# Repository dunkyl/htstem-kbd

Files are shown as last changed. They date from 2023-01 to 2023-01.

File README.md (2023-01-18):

# HTSTEM Keyboard

CAD files for the HTSTEM keyboard.

## Macro12

Test board for the project. 12 keys, 12 addressible LEDs, and rotary encoder. First time I've actually gone through with ordering a PCB to be made.

Source code for firmware is at [another repo](https://github.com/dunkyl/dunkylmacro12).

BOM for macro12:

| Quantity | Description | Link | Note |
| --- | --- | --- | --- |
| 1 | Teensy 2.0 | https://www.pjrc.com/store/teensy.html | Or any compatible microcontroller. I used an [Elite-C from Keebio](https://keeb.io/collections/diy-parts/products/elite-c-low-profile-version-usb-c-pro-micro-replacement-atmega32u4) |
| 1 | PEC11 12mm Rotary Encoder | https://www.digikey.com/en/products/detail/bourns-inc/PEC11L-4220F-S0015/2440942 | |
| 1 | Knob | https://www.digikey.com/en/products/detail/sparkfun-electronics/COM-10001/7229870 | Any knob really |
| 12 | Addressible LED SK6812MINI-E Reverse Mount | https://www.adafruit.com/product/4960 | 10 pack so buy qty 2 |
| 12 | Diode 1N4148FS-ND | https://www.digikey.com/en/products/detail/onsemi/1N4148/458603?s=N4IgTCBcDaIIwDkAsckA4BiBlAtAgIiALoC%2BQA | Or similiar |
| 12 | Key Switch | - | Your choice |
| 12 | Key Cap | - | Your choice |
| 1 | 3D Printed Case | - | Source files here |
| 1 | PCB | - | Source files here |
| 4 | Rubber Feet | https://www.adafruit.com/product/550 | Optional |
| - | Some tape | - | To hold the case halves together. |

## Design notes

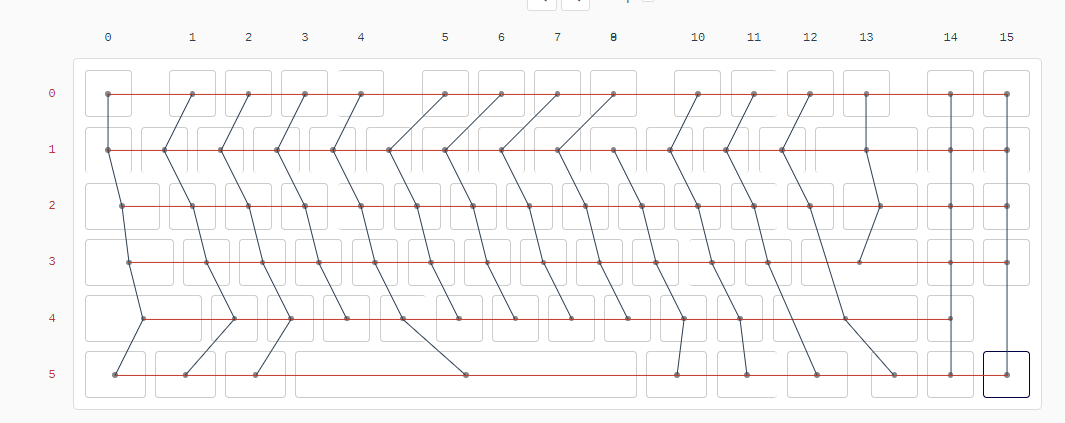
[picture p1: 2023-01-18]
keyboard/Screenshot 2022-04-16 083857.png

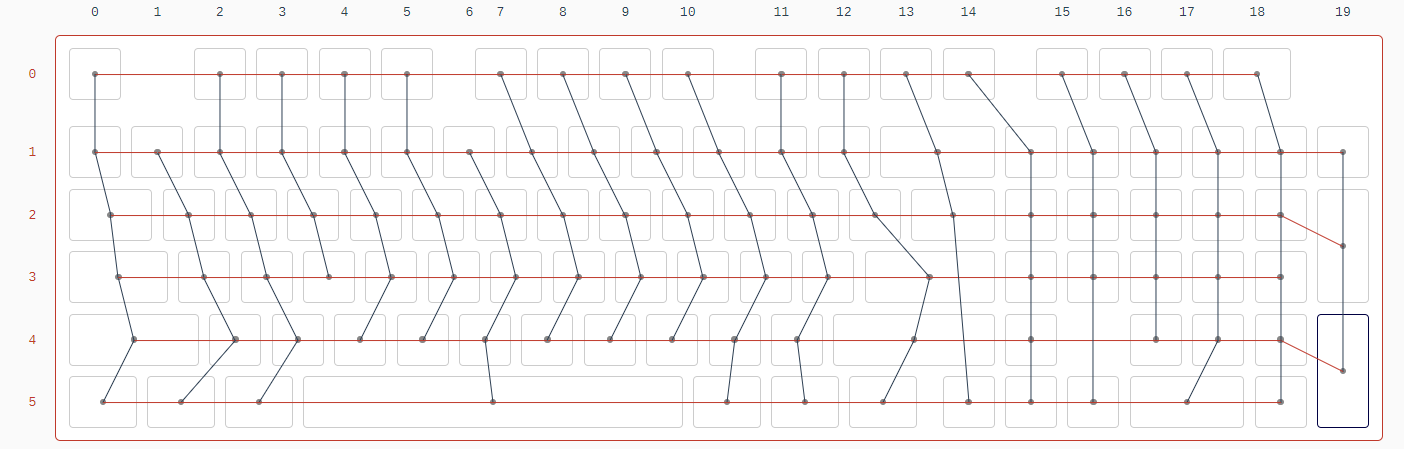
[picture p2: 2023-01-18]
keyboard/Screenshot 2021-11-04 011222.png

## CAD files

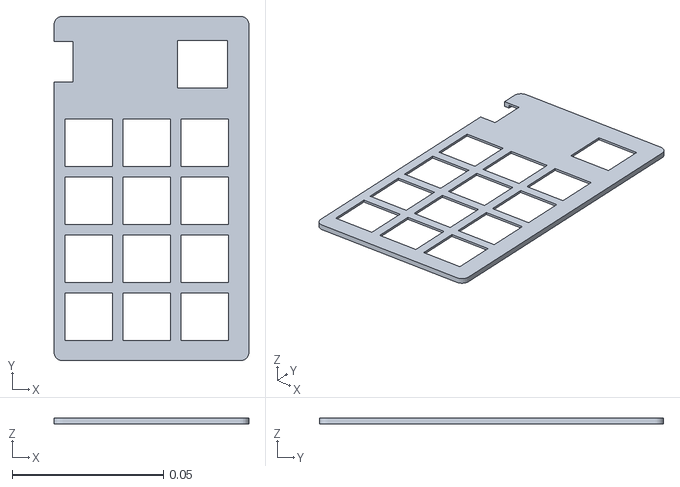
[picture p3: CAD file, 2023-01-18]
macro12/3D Print/lid.stl
0.0645 x 0.114 x 0.00185

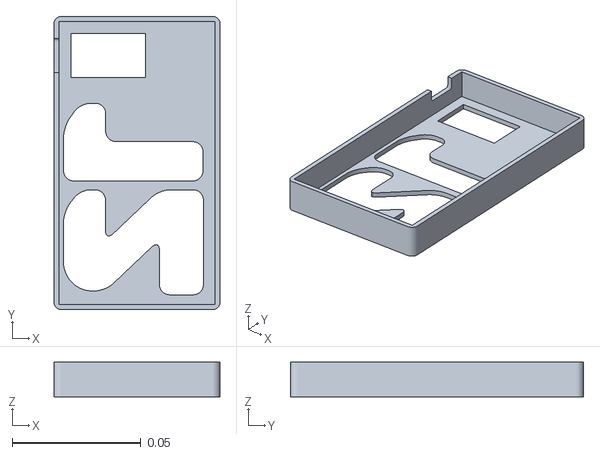
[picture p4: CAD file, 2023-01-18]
macro12/3D Print/casebottom.stl
0.0645 x 0.114 x 0.0135

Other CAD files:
htstem keyboard.blend

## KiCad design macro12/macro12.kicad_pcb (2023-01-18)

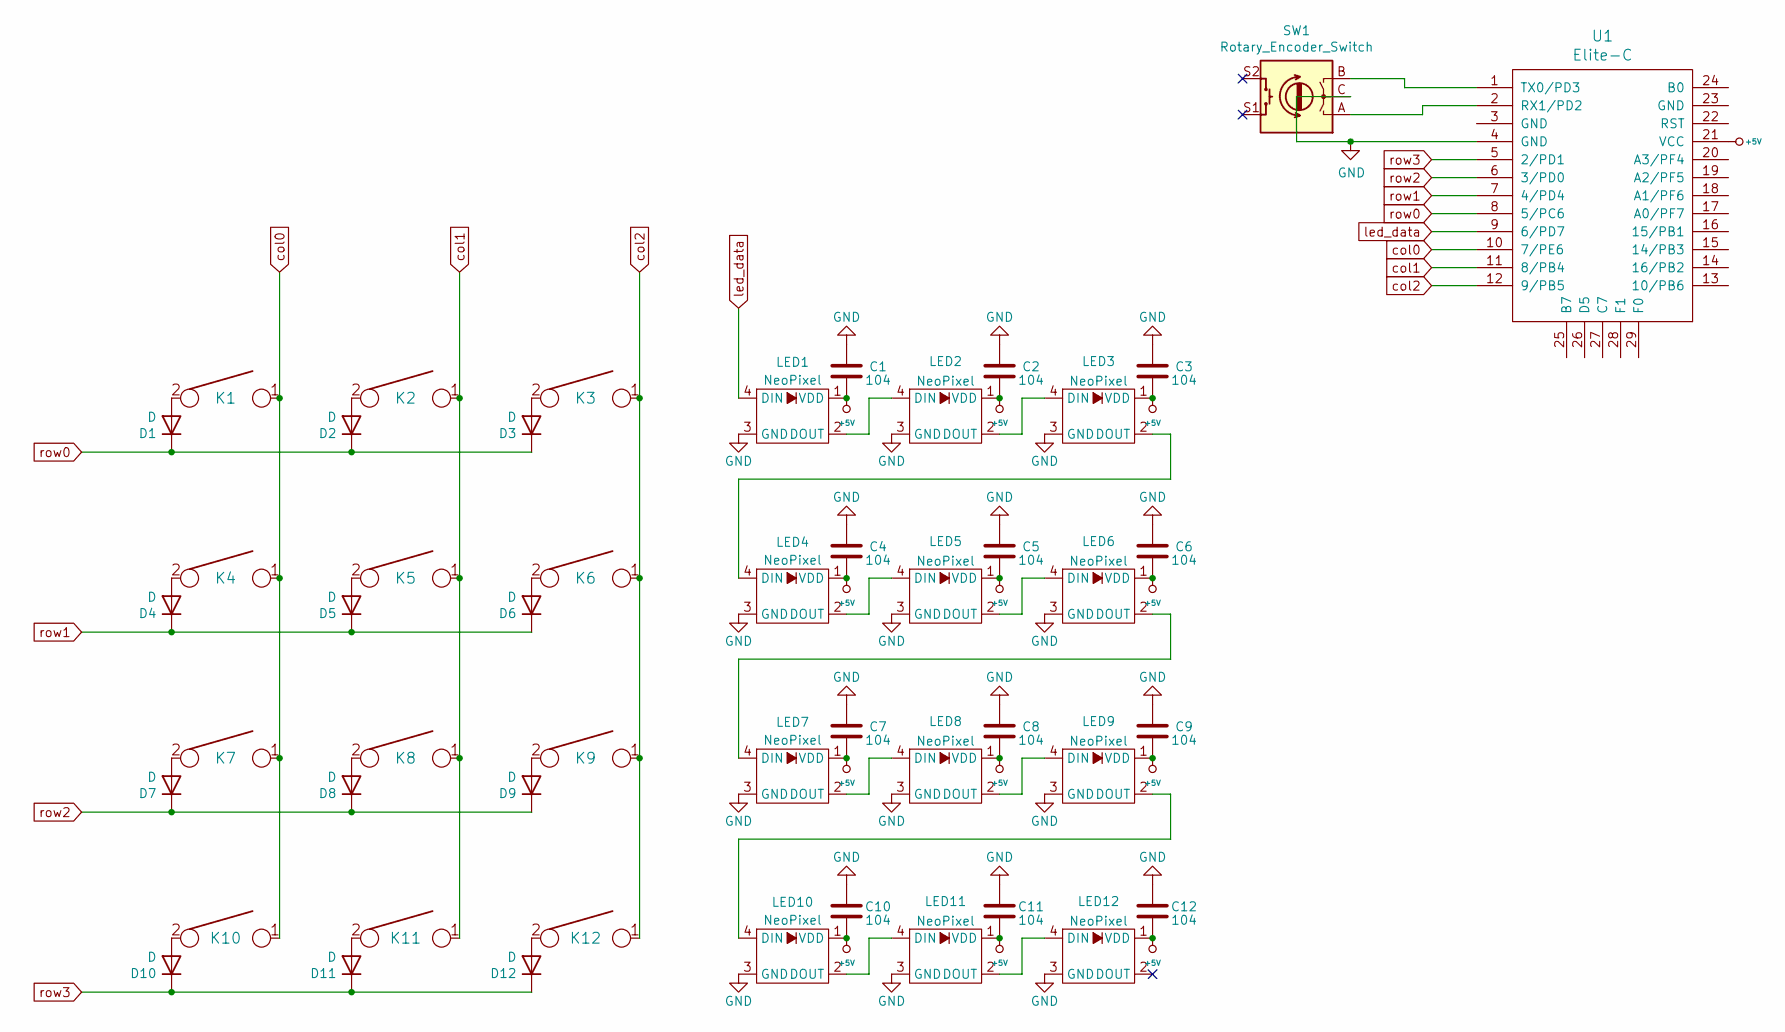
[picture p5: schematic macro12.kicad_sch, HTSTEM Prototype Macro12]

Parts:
C1, C2, C3, C4, C5, C6, C7, C8, C9, C10, C11, C12: 104; C_0805_2012Metric_Pad1.18x1.45mm_HandSolder
D1, D2, D3, D4, D5, D6, D7, D8, D9, D10, D11, D12: D; D_SOD123_axial
K1, K2, K3, K4, K5, K6, K7, K8, K9, K10, K11, K12: KEYSW; Mx_Alps_100
LED1, LED2, LED3, LED4, LED5, LED6, LED7, LED8, LED9, LED10, LED11, LED12: NeoPixel; Adafruit NeoPixel SK6812_E
SW1: Rotary_Encoder_Switch; RotaryEncoder_Alps_EC11E-Switch_Vertical_H20mm
U1: Elite-C; Elite-C-castellated-29pin-holes

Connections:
+5V: C1.1, C2.1, C3.1, C4.1, C5.1, C6.1, C7.1, C8.1, C9.1, C10.1, C11.1, C12.1, LED1.1 (VDD), LED2.1 (VDD), LED3.1 (VDD), LED4.1 (VDD), LED5.1 (VDD), LED6.1 (VDD), LED7.1 (VDD), LED8.1 (VDD), LED9.1 (VDD), LED10.1 (VDD), LED11.1 (VDD), LED12.1 (VDD), U1.21 (VCC)
GND: C1.2, C2.2, C3.2, C4.2, C5.2, C6.2, C7.2, C8.2, C9.2, C10.2, C11.2, C12.2, LED1.3 (GND), LED2.3 (GND), LED3.3 (GND), LED4.3 (GND), LED5.3 (GND), LED6.3 (GND), LED7.3 (GND), LED8.3 (GND), LED9.3 (GND), LED10.3 (GND), LED11.3 (GND), LED12.3 (GND), SW1.C, U1.4 (GND)
unnamed: D1.2 (A), K1.2
unnamed: D2.2 (A), K2.2
unnamed: D3.2 (A), K3.2
unnamed: D4.2 (A), K4.2
unnamed: D5.2 (A), K5.2
unnamed: D6.2 (A), K6.2
unnamed: D7.2 (A), K7.2
unnamed: D8.2 (A), K8.2
unnamed: D9.2 (A), K9.2
unnamed: D10.2 (A), K10.2
unnamed: D11.2 (A), K11.2
unnamed: D12.2 (A), K12.2
unnamed: LED1.2 (DOUT), LED2.4 (DIN)
unnamed: LED2.2 (DOUT), LED3.4 (DIN)
unnamed: LED3.2 (DOUT), LED4.4 (DIN)
unnamed: LED4.2 (DOUT), LED5.4 (DIN)
unnamed: LED5.2 (DOUT), LED6.4 (DIN)
unnamed: LED6.2 (DOUT), LED7.4 (DIN)
unnamed: LED7.2 (DOUT), LED8.4 (DIN)
unnamed: LED8.2 (DOUT), LED9.4 (DIN)
unnamed: LED10.2 (DOUT), LED11.4 (DIN)
unnamed: LED9.2 (DOUT), LED10.4 (DIN)
unnamed: LED11.2 (DOUT), LED12.4 (DIN)
unnamed: SW1.A, U1.2 (RX1/PD2)
unnamed: SW1.B, U1.1 (TX0/PD3)
col0: K1.1, K4.1, K7.1, K10.1, U1.10 (7/PE6)
col1: K2.1, K5.1, K8.1, K11.1, U1.11 (8/PB4)
col2: K3.1, K6.1, K9.1, K12.1, U1.12 (9/PB5)
led_data: LED1.4 (DIN), U1.9 (6/PD7)
row0: D1.1 (K), D2.1 (K), D3.1 (K), U1.8 (5/PC6)
row1: D4.1 (K), D5.1 (K), D6.1 (K), U1.7 (4/PD4)
row2: D7.1 (K), D8.1 (K), D9.1 (K), U1.6 (3/PD0)
row3: D10.1 (K), D11.1 (K), D12.1 (K), U1.5 (2/PD1)

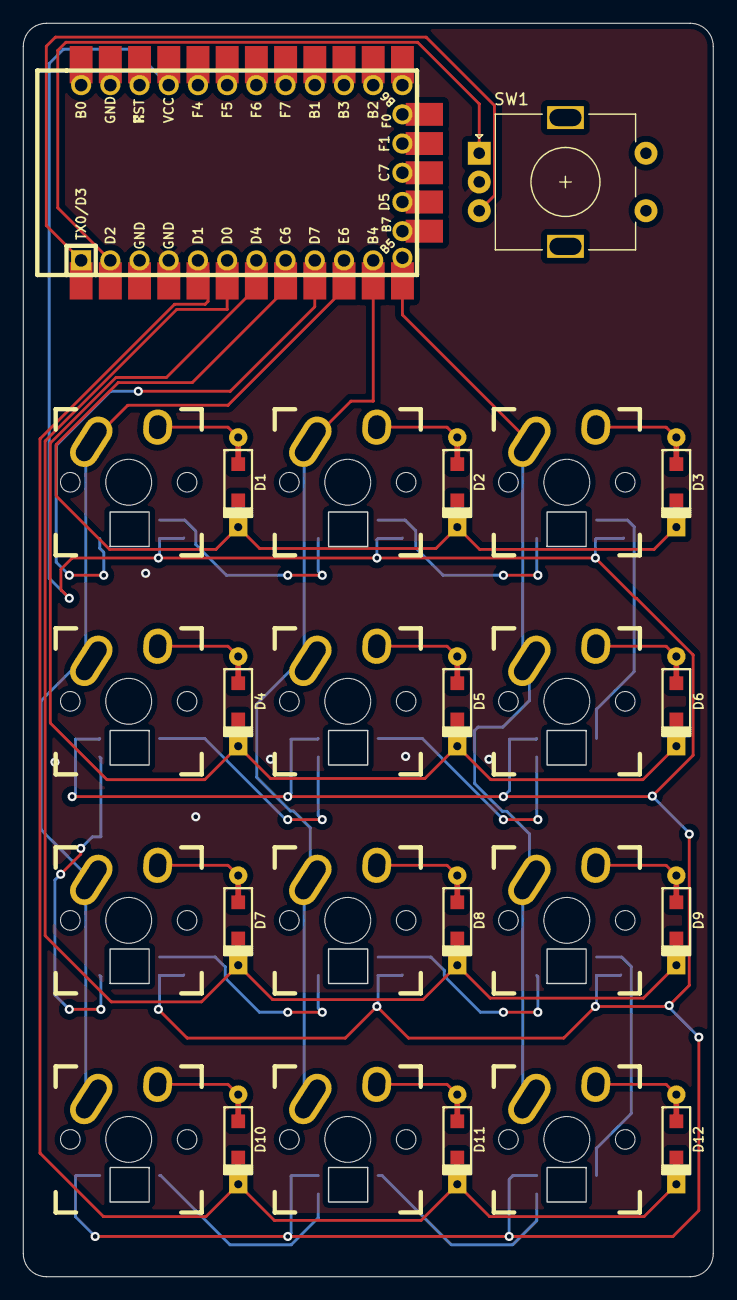
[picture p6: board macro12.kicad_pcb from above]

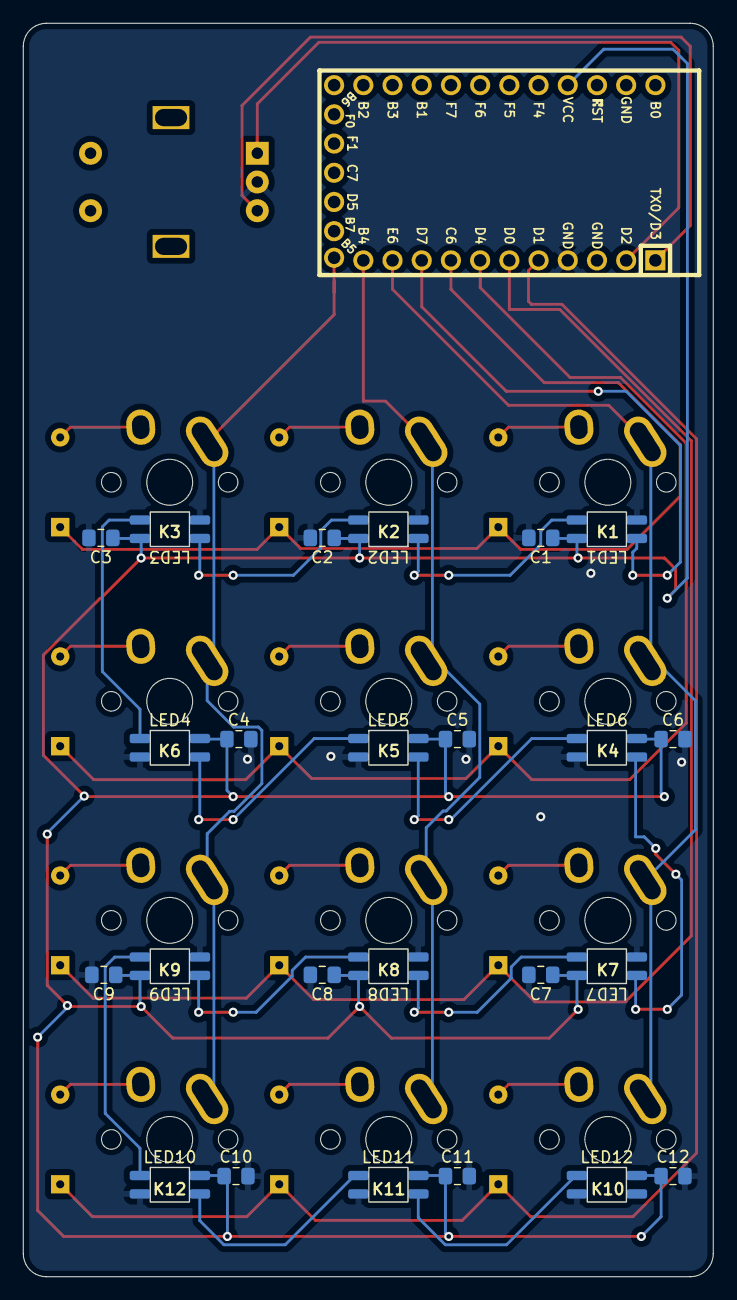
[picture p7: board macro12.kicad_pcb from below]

Board: 2 copper layers, 60.0 x 109.0 mm, 50 parts (24 on the bottom side), 35 nets.
